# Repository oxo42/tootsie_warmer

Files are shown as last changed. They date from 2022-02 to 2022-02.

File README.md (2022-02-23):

# tootsie_warmer

Arudino controlled boot warmer using a Wemos D1 mini (ESP8266 variant) that can be controlled by Home Assitant over MQTT.

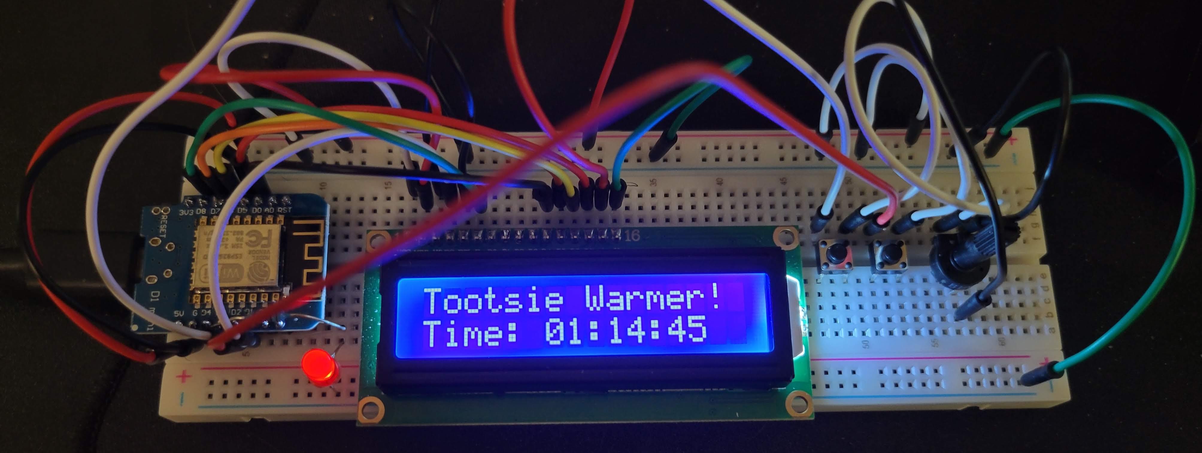
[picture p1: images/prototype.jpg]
Breadboard prototype


Pretend the LED is a relay that switches on the boot warmer

The circuit diagram for this is

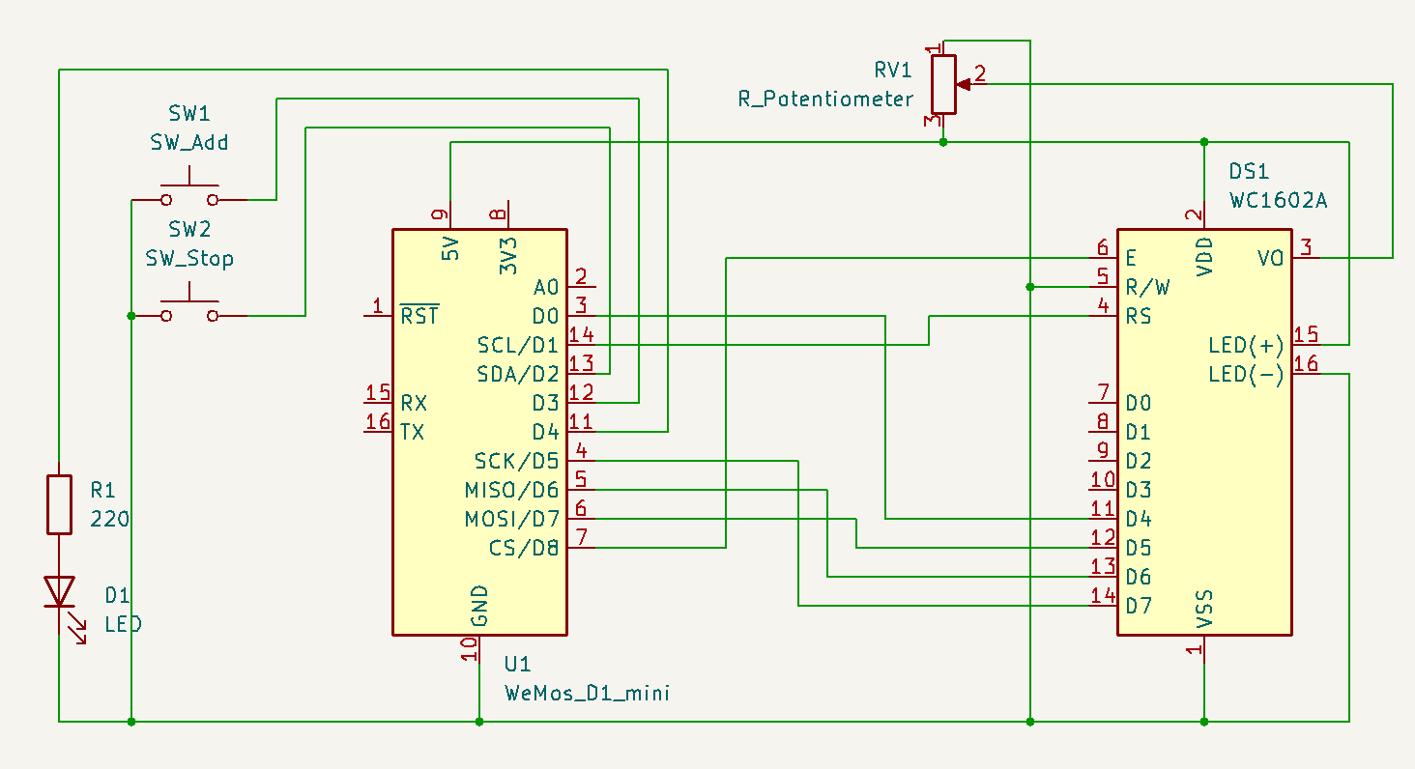
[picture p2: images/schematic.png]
Schematic


## How does it work - Physical

* Pressing `SW_Add` (the lefthand button in the prototype) will add 15 minutes to a timer
* Pressing `SW_stop` will clear the timer and turn off the LED

## MQTT & Home Assistant

All communications happen over MQTT.

### Sensor Discovery

The device shows up in home assistant as a sensor in the active or idle states.

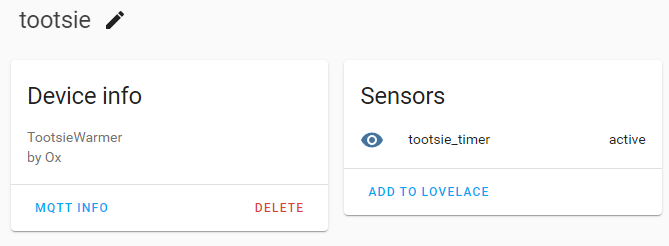
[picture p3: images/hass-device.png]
Home Assistant Device


It has attributes of `duration` and `remaining` showing how long is left.  These fit really well with the [Lovelace Timer Bar Card](https://github.com/rianadon/timer-bar-card).  There is a weird thing with the timer bar card that it loses between 5 and 10 seconds due to how it works out time remaining.  I might fix this in https://github.com/oxo42/tootsie_warmer/issues/1

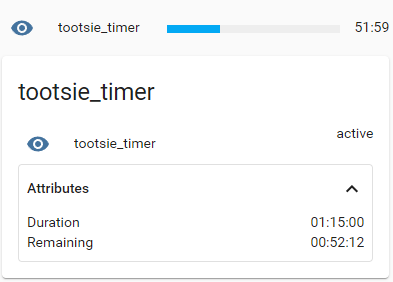
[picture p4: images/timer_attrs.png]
Timer with attributes


### Setting the timer remotely

Sending an integer to the MQTT topic `homeassistant/sensor/tootsie/set` will set the timer to that many seconds.  Once this is all hooked up, I intend HASS to send 3600s at 7am, just in time for me to leave at 8.

## But why?

I want to overengineer my boot warmer so that [Home Assistant](https://www.home-assistant.io/) can turn it on for me at 7am and I have warm ski boots at 8am. My intention is to pull the spring based timer out of a set of boot warmer and replace it with an arduino that controls a relay.

### Would it have been simpler to bypass the spring switch and use an off the shelf smart plug to control it?

You're not my friend any more, go away!

## Hardware gotchas

### Pin D8 cannot be held high at boot

At one point I had pin D8 connected to a pin on the LCD1602 that was high at boot and caused the boot to fail.

## References

* [ESP8266 Pinout Reference](https://randomnerdtutorials.com/esp8266-pinout-reference-gpios/)
* [Timer Bar Card](https://github.com/rianadon/timer-bar-card)

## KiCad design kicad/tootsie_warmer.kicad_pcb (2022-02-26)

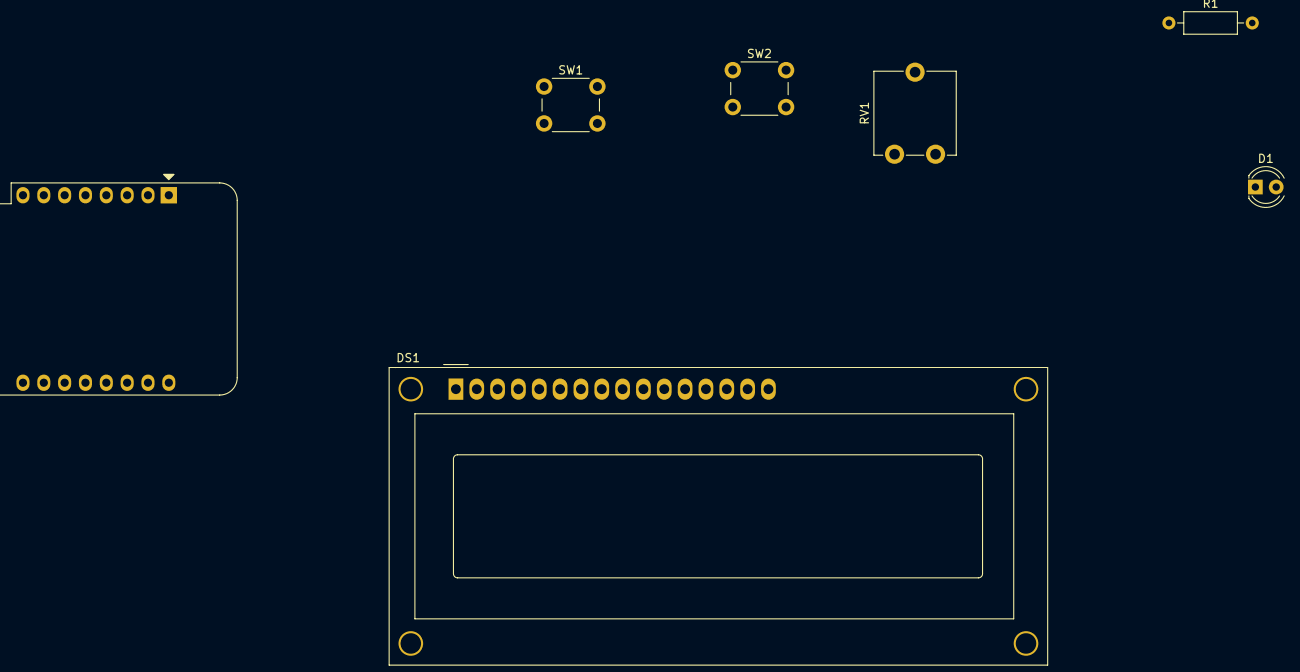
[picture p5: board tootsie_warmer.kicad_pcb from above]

Board: 2 copper layers, 7 parts (0 on the bottom side), 13 nets, no tracks yet.

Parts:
D1: LED; LED_D4.0mm
DS1: WC1602A
R1: 220; R_Axial_DIN0207_L6.3mm_D2.5mm_P10.16mm_Horizontal
RV1: R_Potentiometer; Potentiometer_ACP_CA9-V10_Vertical
SW1: SW_Add; SW_PUSH_6mm_H4.3mm
SW2: SW_Stop; SW_PUSH_6mm_H4.3mm
U1: WeMos_D1_mini; WEMOS_D1_mini_light

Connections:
unnamed: D1.2 (A), R1.2
unnamed: DS1.3 (VO), RV1.2
unnamed: DS1.4 (RS), U1.14 (SCL/D1)
unnamed: DS1.6 (E), U1.7 (CS/D8)
unnamed: DS1.11 (D4), U1.3 (D0)
unnamed: DS1.12 (D5), U1.6 (MOSI/D7)
unnamed: DS1.13 (D6), U1.5 (MISO/D6)
unnamed: DS1.14 (D7), U1.4 (SCK/D5)
unnamed: R1.1, U1.11 (D4)
unnamed: SW1.2, U1.12 (D3)
unnamed: SW2.2, U1.13 (SDA/D2)
unnamed: DS1.2 (VDD), DS1.15 (LED(+)), RV1.3, U1.9 (5V)
unnamed: D1.1 (K), DS1.1 (VSS), DS1.5 (R/W), DS1.16 (LED(-)), RV1.1, SW1.1, SW2.1, U1.10 (GND)

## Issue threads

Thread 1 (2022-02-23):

Time bar card misses 5 - 10 seconds

oxo42, 2022-02-23:
Due to the way the [`timeRemaining` is calculated](https://github.com/rianadon/timer-bar-card/blob/main/src/helpers.ts#L49), timer bar card loses about 5-10 seconds.  See below image.

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

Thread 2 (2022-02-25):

Connect relay to D2 instead of D4

oxo42, 2022-02-25:
I want to have my relay in a situation of low is off, so if anything goes wrong with the arduino, it switches off. According to the [ESP8266 Pinout Reference Guide](https://randomnerdtutorials.com/esp8266-pinout-reference-gpios/), D4 is **high at boot**.

Swap pins D2 and D4 to fix this

Closed 2022-02-26.

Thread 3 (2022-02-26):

Split schema into two boards

oxo42, 2022-02-26:
# Board 1

* Arduino
* Connector to relay
* Connector to LCD+Button Board

# Board 2

* LCD
* Add button
* Stop button

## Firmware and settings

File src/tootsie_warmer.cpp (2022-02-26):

// John Oxley
// Over-engineered boot warmer

#include <Arduino.h>
#include <AsyncTimer.h>
#include <EspMQTTClient.h>
#include <LiquidCrystal.h>
#include <ESP8266Wifi.h>
#include <HAMqttDevice.h>

#include "tootsie.h"

#define RELAY_PIN D2
#define BUTTON_ADD D3
#define BUTTON_STOP D4
#define ADD_SECONDS 15 * 60
#define MAX_SECONDS 180 * 60

#define EXPIRE_AFTER "180"
#define ALIVE_TIMEOUT 120 * 1000

EspMQTTClient client(
    "LAN Solo",
    "smallandpoopy",
    "10.0.0.2",
    "BootWarmer" // Client name that uniquely identify your device
);
AsyncTimer t;
int timer_id = 0;
int log_timer_id = 0;
int alive_timer_id = 0;
int total_time_ms = 0;
LiquidCrystal lcd(D1, D8, D0, D7, D6, D5);

HAMqttDevice tootsie_timer("tootsie_timer", HAMqttDevice::SENSOR, "homeassistant");

void logTimeLeft();
void onSetMessageReceived(const String &payload);
void stop();

void sendConfig()
{
  client.publish(tootsie_timer.getConfigTopic(), tootsie_timer.getConfigPayload());
  logTimeLeft();
}

void sendDurationRemaining(unsigned int seconds_left)
{
  tootsie_timer.clearAttributes();
  tootsie_timer.addAttribute("duration", duration_to_timestamp(total_time_ms / 1000));
  tootsie_timer.addAttribute("remaining", duration_to_timestamp(seconds_left));
  client.publish(tootsie_timer.getAttributesTopic(), tootsie_timer.getAttributesPayload());
  if (seconds_left > 0)
    client.publish(tootsie_timer.getStateTopic(), "active");
  else
    client.publish(tootsie_timer.getStateTopic(), "idle");
}

void onConnectionEstablished()
{
  Serial.println("MQTT Connection Established");
  sendConfig();
  client.subscribe("homeassistant/sensor/tootsie/set", onSetMessageReceived);
  if (alive_timer_id <= 0)
    alive_timer_id = t.setInterval(logTimeLeft, ALIVE_TIMEOUT);
}

void setup()
{
  Serial.begin(115200);
  Serial.println("");
  Serial.println("Setting up buttons");

  pinMode(RELAY_PIN, OUTPUT);
  pinMode(BUTTON_ADD, INPUT_PULLUP);
  pinMode(BUTTON_STOP, INPUT_PULLUP);

  // set up the LCD's number of columns and rows:
  lcd.begin(16, 2);
  // Print a message to the LCD.
  lcd.print("Tootsie Warmer!");
  lcd.setCursor(0, 1);
  lcd.print("Idle");
  client.setMaxPacketSize(1024);

  HAMqttDeviceRegistry dev;
  dev.addAttribute("name", "tootsie");
  dev.addAttribute("model", "TootsieWarmer");
  dev.addAttribute("manufacturer", "Ox");
  dev.addIdentifier(WiFi.macAddress());

  tootsie_timer.addConfigVar("expire_after", "180");
  tootsie_timer.addConfigVar("force_update", "true ");
  tootsie_timer.addConfigVar("dev", dev.getPayload());
  tootsie_timer.enableAttributesTopic();

  Serial.println("Initialisation Complete");
}

void logTimeLeft()
{
  if (timer_id > 0)
  {
    unsigned long seconds_left = t.getRemaining(timer_id) / 1000;
    sendDurationRemaining(seconds_left);
    Serial.print("Seconds left: ");
    Serial.println(seconds_left);
    lcd.setCursor(0, 1);
    lcd.print("Time: ");
    lcd.print(duration_to_timestamp(seconds_left));
    lcd.print("   ");
  }
  else
  {
    sendDurationRemaining(0);
  }
}

void addTime(int add_ms)
{
  Serial.print("Adding ");
  Serial.print(add_ms);
  Serial.println(" ms.");

  digitalWrite(RELAY_PIN, HIGH);
  if (timer_id > 0)
  {
    if ((total_time_ms + add_ms) <= MAX_SECONDS * 1000)
    {
      // Timer exists, add time
      t.delay(timer_id, add_ms);
      total_time_ms += add_ms;
    }
    else
    {
      Serial.println("Time too large, refusing to add");
    }
  }
  else
  {
    timer_id = t.setTimeout(stop, add_ms);
    log_timer_id = t.setInterval(logTimeLeft, 1000);
    total_time_ms = add_ms;
  }
  logTimeLeft();
}

void setTime(int ms)
{
  Serial.print("Setting timer to: ");
  Serial.println(ms);
  stop();
  addTime(ms);
}

void stop()
{
  digitalWrite(RELAY_PIN, LOW);
  Serial.println("Stopping timer");
  sendDurationRemaining(0);
  if (timer_id > 0)
  {
    t.cancel(timer_id);
  }
  t.cancel(log_timer_id);
  timer_id = 0;
  lcd.setCursor(0, 1);
  lcd.print("Idle           ");
}

void loop()
{
  t.handle();
  client.loop();

  if (digitalRead(BUTTON_ADD) == LOW)
  {
    addTime(ADD_SECONDS * 1000);
    delay(250);
  }
  if (digitalRead(BUTTON_STOP) == LOW)
  {
    stop();
    delay(250);
  }
}

void onSetMessageReceived(const String &payload)
{
  int ms = payload.toInt() * 1000;
  setTime(ms);
}

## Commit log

2022-02-22 Fix up timer stuff
    [tootsie_warmer.cpp]
2022-02-22 Bring device registry class into my project
2022-02-23 Add kicad files
    [tootsie_warmer.kicad_pcb, tootsie_warmer.kicad_sch]
2022-02-23 Updated timer attrs in readme
2022-02-26 Update state every 2 minutes to avoid going unavailable
    [tootsie_warmer.cpp]
2022-02-26 Update schema to have connector for relay
    [tootsie_warmer.kicad_pcb, tootsie_warmer.kicad_sch]
2022-02-26 Swap D2 & D4. Fixes #2
    [tootsie_warmer.kicad_sch]
2022-03-01 Update kicad gitignore

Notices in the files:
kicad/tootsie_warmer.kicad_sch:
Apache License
